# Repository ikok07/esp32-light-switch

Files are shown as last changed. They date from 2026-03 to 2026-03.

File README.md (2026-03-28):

# ESP32 Light Switch

A BLE-enabled smart light switch built on the **ESP32**, developed as part of a custom hardware product lineup. The firmware is written in C using the **ESP-IDF** framework and integrates natively with **Home Assistant** via a custom dedicated [HAOS BLE integration](https://github.com/ikok07/kok-products-ble-haos-integration).

---

## Features

- **BLE Control** — Toggle the light on/off wirelessly from any BLE-capable client (preferably the HAOS integration)
- **Physical Toggle** — Interrupt-driven physical button for manual control (GPIO 21)
- **Home Assistant Integration** — Works out of the box with my custom [HAOS BLE integration](https://github.com/ikok07/kok-products-ble-haos-integration)
- **Status LED** — RGB LED (GPIO 48) that reflects the current device state at a glance
- **Light Sleep** — CPU frequency scaling and light sleep enabled at runtime to reduce power consumption
- **Dual-core task scheduling** — BLE stack runs on Core 0; light control, status LED, and notification tasks run on Core 1

---

## Hardware

The PCB design files are located in the [`pcb/`](pcb/) directory (KiCad project). Key datasheets and reference material can be found in [`docs/`](docs/).

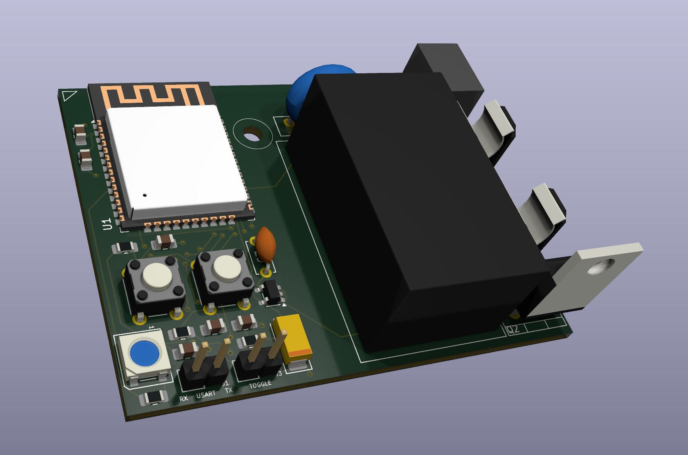
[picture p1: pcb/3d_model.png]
PCB 3D-model


| Component | Purpose |
|---|---|
| ESP32 | Main MCU |
| BTB16 - TRIAC | Mains switching |
| HLK-PM01 | AC→5 V power supply |
| MIC5205 LDO | 3.3 V regulation |
| PC817 Optocoupler | TRIAC isolation |

---

## Firmware Overview

The project is structured as a standard ESP-IDF project with reusable components:

```
main/           – Application entry point & board-specific configuration
components/
  ├── app_state/        – Global application state (tasks, handles, shared values)
  ├── ble/              – BLE driver (GAP / GATT abstraction over NimBLE)
  ├── logger/           – Logging utilities
  ├── power/            – CPU frequency control & light sleep management
  ├── shared_values/    – Thread-safe shared value store (FreeRTOS-based)
  ├── tasks_scheduler/  – FreeRTOS task lifecycle helpers
  └── timer/            – Timer utilities
```

### Startup sequence

1. Application state initialised
2. Logger configured
3. Power management configured & CPU frequency scaling enabled
4. Status LED initialised → **orange** (configuring)
5. Light control GPIO and ISR configured
6. BLE stack initialised → status LED turns **white** (ready to connect)
7. Light sleep enabled

### Status LED states

| Color | State |
|---|---|
| 🟠 Orange | Configuring / booting |
| 🔴 Red | Hardware configuration error |
| 🔵 White  | Ready to connect |
| 🟢 Green  | Connected |
| Other | BLE configuration error |

---

## BLE Profile

| Property | Value |
|---|---|
| Device name | `LSwitch` |
| GAP appearance | `0x04C1` (Generic Switch) |
| Advertising interval | 50 ms |
| Security mode | Disabled / Just Works |
| Max connections | Configured via CONFIG_BT_NIMBLE_MAX_CONNECTIONS |
| Serial number | `LS001` |

### GATT Services

| Service | UUID | Description |
|---|---|---|
| Identifier | `651535-36ae-49aa-354c-ecfec15bc888` (128-bit) | Used by the HAOS integration to identify the device family |
| Automation I/O | `0x1815` | Exposes the light state characteristic |

**Light State Characteristic** (`0x2A56` – Digital):
- **Read** — returns current relay state (`0` or `1`)
- **Write** — sets relay state (`0` = off, `1` = on)
- **Notify** — pushes state updates to subscribed clients

---

## Home Assistant Integration

Install the [HAOS BLE integration](https://github.com/ikok07/kok-products-ble-haos-integration) in your Home Assistant instance. The device advertises the identifier service UUID and manufacturer data in its BLE advertisement so that the integration can automatically recognise and add it.

See [`docs/haos_compatibility.md`](docs/haos_compatibility.md) for the full BLE advertisement requirements.

---

## Building & Flashing

Prerequisites: [ESP-IDF v5.x](https://docs.espressif.com/projects/esp-idf/en/latest/esp32s3/get-started/) installed and sourced.

```bash
# Configure
idf.py set-target esp32

# Build
idf.py build

# Flash & monitor
idf.py -p /dev/tty.usbserial-* flash monitor
```

---

## License

This project is part of a custom hardware product lineup. All rights reserved © Kaloyan Stefanov.

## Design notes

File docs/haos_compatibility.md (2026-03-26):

#### To make the device compatible with [Home Assistant integration](https://github.com/ikok07/kok-products-ble-haos-integration) you should configure the following BLE parameters:

----

1. Identifier service should be set in the advertisement fields (check UUID from the [integration's repo](https://github.com/ikok07/kok-products-ble-haos-integration))
2. The encryption mode should be set to "Just Works" (integration doesn't support other methods yet)
3. Advertised manufacturer data:
   - byte 1–2 ⇒ Manufacturer ID (check from the [integration's repo](https://github.com/ikok07/kok-products-ble-haos-integration))
   - byte 3 ⇒ Device Model (must be implemented in [integration's repo](https://github.com/ikok07/kok-products-ble-haos-integration))
   - byte 4 ⇒ If the device requires pairing (0 or 1)

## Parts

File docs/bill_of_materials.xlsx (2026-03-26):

Part | Designator | Quantity | Price | Real Price | URL
ESP32-WROOM-32E | U1 | 1 | €0.00 | €0.00
HLK-PM01 (Power supply) | PS2 | 1 | €4.35 | €4.35 | https://bulcomp-eng.com/m/index.php?p=10&idprod=19925
PC817 (Optocoupler) | U2 | 1 | €0.26 | €0.26 | https://tpetrov.com/ltv817s-lit-247331
BTB16-800BRG (TRIAC) | Q2 | 1 | €1.07 | €1.07 | https://tpetrov.com/btb16-800brg-242340
AC Terminal Screw 01x02 | J2 | 1 | €0.26 | €0.26 | https://tpetrov.com/klema-dg306-02p-36674
MIC5205 (Voltage regulator) | U3 | 1 | €0.00 | €0.00
Capacitor Tantalum (4.7uF) | C5 | 1 | €0.64 | €0.64 | https://tpetrov.com/kondenzator-47mf-25v-smd-tantal-35838
Capacitor (0.1uF) | C1, C4, C6, C8, C9 | 5 | €0.06 | €0.30 | https://tpetrov.com/kondenzator-100nf-50v-0805-smd-34785
Capacitor (470pF) | C7 | 1 | €0.08 | €0.08 | https://tpetrov.com/kondenzator-470pf-100v-47046
Capacitor (22uF) | C2 | 1 | €0.10 | €0.10 | https://tpetrov.com/kondenzator-22mf-63v-smd-0805-243684
Resistor (220) | R4 | 1 | €0.08 | €0.08 | https://tpetrov.com/rezistor-220om-smd-0805-250613
Resistor (10K) | R1, R2, R3 | 3 | €0.03 | €0.09 | https://tpetrov.com/rezistor-10kom-smd-0805-22597
Resistor (100) | R5, R6 | 2 | €0.06 | €0.12 | https://tpetrov.com/rezistor-100om-0125w-smd-22589
Touch button | SW1, SW2 | 2 | €0.09 | €0.18 | https://tpetrov.com/tach-buton-121-9505
Toggle button | J3 | 1 | €0.97 | €0.97 | https://tpetrov.com/buton-swb1019a-r-240936
Varistor 275V | RV1 | 1 | €0.36 | €0.36 | https://tpetrov.com/varistor-275v-125mm-240814
Fuse (500mA) | F1 | 1 | €0.10 | €0.10 | https://tpetrov.com/predpazitel-5x20-05a-zkm-36366
Fuse holder | - | 1 | €0.26 | €0.26 | https://tpetrov.com/darjach-za-predpazitel-f313-5x20-39121
Connector (Male & Female) | - | 1 | €0.10 | €0.10 | https://tpetrov.com/kuplung-396-ns39-02mg-46470
Heatsink (TRIAC) | - | 1 | €0.51 | €0.51 | https://tpetrov.com/radiator-n23-40566
WS2812B LED | D1 | 1 | €0.00 | €0.00 | -
 |  |  |  | €9.83

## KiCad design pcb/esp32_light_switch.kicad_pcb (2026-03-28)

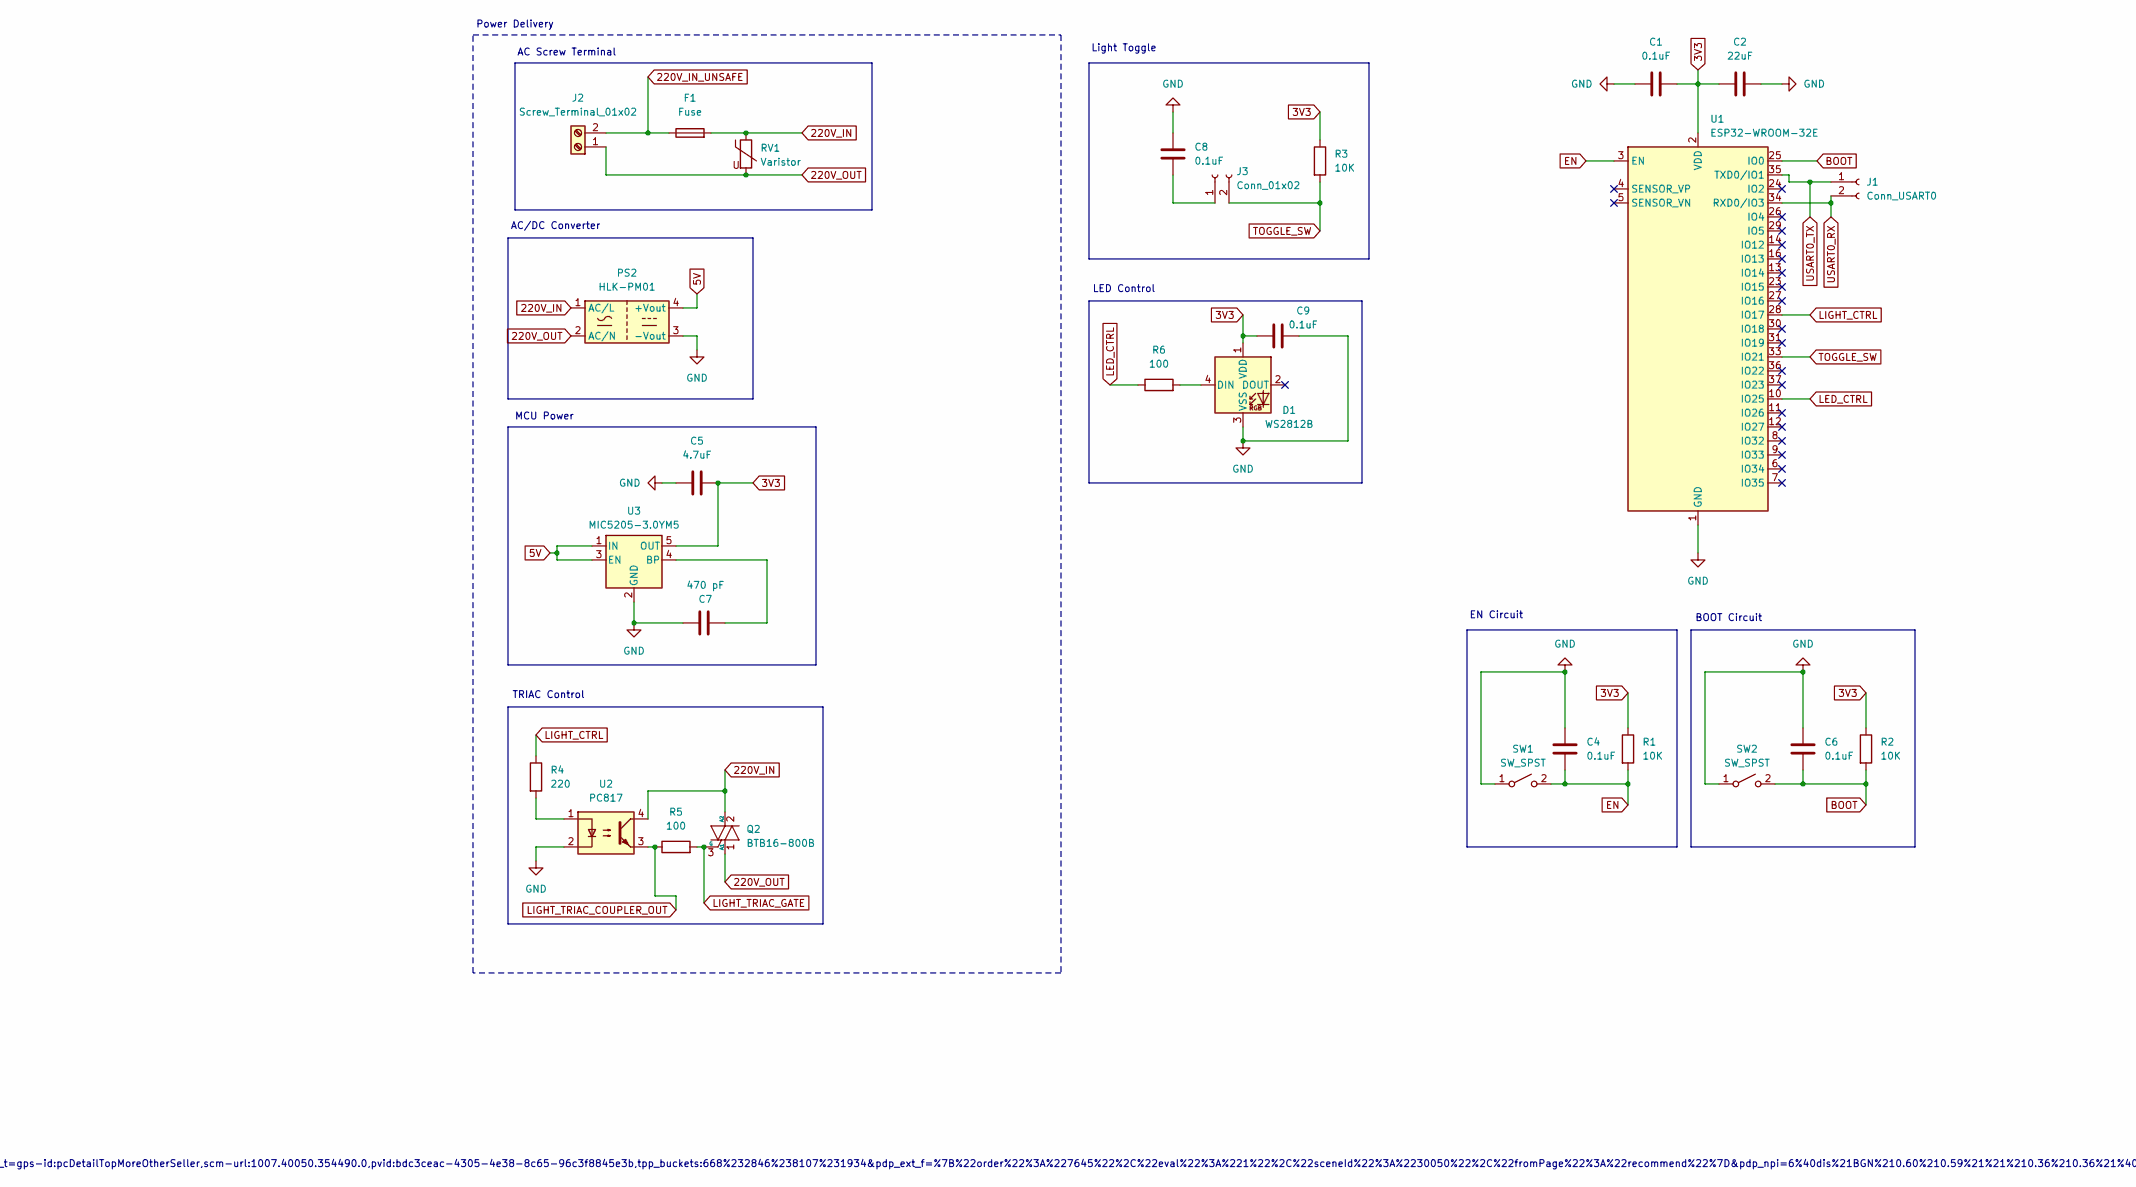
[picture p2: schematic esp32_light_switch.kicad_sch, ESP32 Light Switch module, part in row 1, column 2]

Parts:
C1, C4, C6, C8, C9: 0.1uF; C_0805_2012Metric_Pad1.18x1.45mm_HandSolder
C2: 22uF; C_0805_2012Metric_Pad1.18x1.45mm_HandSolder
C5: 4.7uF; CP_EIA-6032-20_AVX-F_HandSolder
C7: 470 pF; C_Disc_D5.0mm_W2.5mm_P5.00mm
D1: WS2812B; LED_WS2812B_PLCC4_5.0x5.0mm_P3.2mm
F1: Fuse; Fuseholder_Cylinder-5x20mm_Schurter_0031_8201_Horizontal_Op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
J1: Conn_USART0; PinHeader_1x02_P2.54mm_Vertical
J2: Screw_Terminal_01x02; DG3065002P1200AH
J3: Conn_01x02; PinHeader_1x02_P2.54mm_Vertical
PS2: HLK-PM01; Converter_ACDC_Hi-Link_HLK-PMxx
Q2: BTB16-800B; TO-220-3_Vertical
R1, R2, R3: 10K; R_0805_2012Metric_Pad1.20x1.40mm_HandSolder
R4: 220; R_0805_2012Metric_Pad1.20x1.40mm_HandSolder
R5, R6: 100; R_0805_2012Metric_Pad1.20x1.40mm_HandSolder
RV1: Varistor; RV_Disc_D12mm_W3.9mm_P7.5mm
SW1, SW2: SW_SPST; SW_TH_Tactile_Omron_B3F-100x
U1: ESP32-WROOM-32E; ESP32-WROOM-32D
U2: PC817; DIP-4_W7.62mm_SMDSocket_SmallPads
U3: MIC5205-3.0YM5; SOT-23-5

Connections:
3V3: C1.2, C2.1, C5.2, C9.1, D1.1 (VDD), R1.1, R2.1, R3.1, U1.2 (VDD), U3.5 (OUT)
5V: PS2.4 (+Vout), U3.1 (IN), U3.3 (EN)
220V_IN: F1.2, PS2.1 (AC/L), Q2.2 (A2), RV1.1, U2.4
220V_IN_UNSAFE: F1.1, J2.2
220V_OUT: J2.1, PS2.2 (AC/N), Q2.1 (A1), RV1.2
BOOT: C6.1, R2.2, SW2.2 (B), U1.25 (IO0)
EN: C4.2, R1.2, SW1.2 (B), U1.3 (EN)
GND: C1.1, C2.2, C4.1, C5.1, C6.2, C7.2, C8.1, C9.2, D1.3 (VSS), PS2.3 (-Vout), SW1.1 (A), SW2.1 (A), U1.1 (GND), U1.15 (GND), U1.38 (GND), U1.39 (GND), U2.2, U3.2 (GND)
LED_CTRL: R6.1, U1.10 (IO25)
LIGHT_CTRL: R4.1, U1.28 (IO17)
LIGHT_TRIAC_COUPLER_OUT: R5.1, U2.3
LIGHT_TRIAC_GATE: Q2.3 (G), R5.2
unnamed: D1.4 (DIN), R6.2
unnamed: C8.2, J3.1
unnamed: R4.2, U2.1
unnamed: C7.1, U3.4 (BP)
TOGGLE_SW: J3.2, R3.2, U1.33 (IO21)
USART0_RX: J1.2, U1.34 (RXD0/IO3)
USART0_TX: J1.1, U1.35 (TXD0/IO1)

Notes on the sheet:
TRIAC Control
Light Toggle
AC Screw Terminal
Power Delivery
LED Control
AC/DC Converter
BOOT Circuit
https://www.aliexpress.com/item/32901160058.html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…
MCU Power
EN Circuit

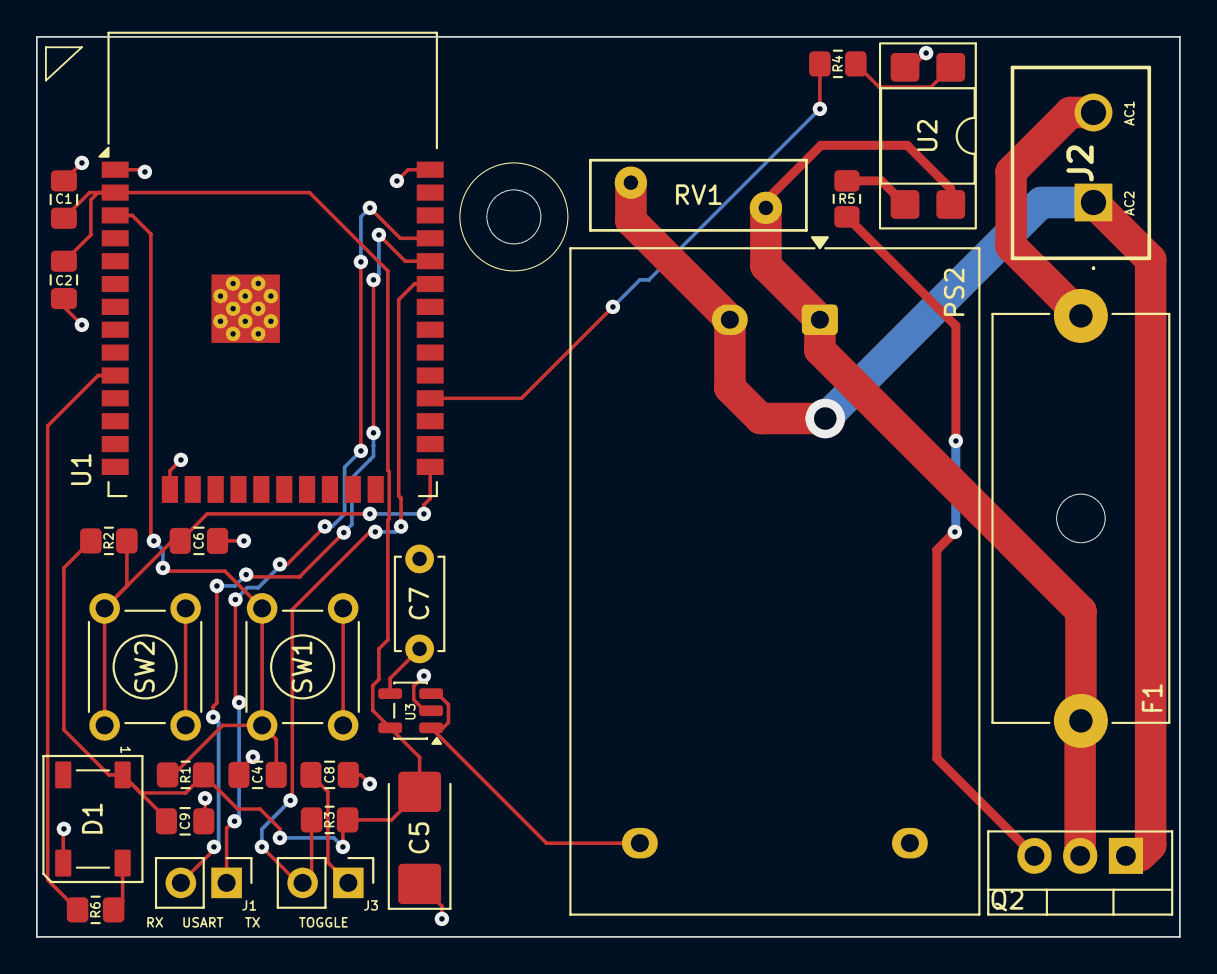
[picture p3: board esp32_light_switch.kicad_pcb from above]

Board: 2 copper layers, 63.5 x 50.0 mm, 27 parts (0 on the bottom side), 19 nets.

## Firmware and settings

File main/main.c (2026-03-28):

#include "app_state.h"
#include "power.h"
#include "log.h"
#include "ble.h"
#include "led_strip.h"

#include "bt.h"
#include "log-config.h"
#include "light_control.h"
#include "status_led.h"


void app_main(void) {
    esp_err_t esp_err;

    // Initialize app state
    APP_Init();

    // Configure logger
    LOG_Configure();

    // Configure power
    if ((esp_err = POWER_Config())!= ESP_OK) {
        LOGGER_LogF(LOGGER_LEVEL_FATAL, "Failed to configure board power! Error code: %d", esp_err);
        return;
    }
    POWER_FreqControl(pdTRUE);

    // Disable MCU sleep during configuration
    POWER_LightSleepControl(pdFALSE);

    // Configure Status LED
    STATUSLED_Init();

    // Set configuring LED state
    STATUSLED_SetState(STATUSLED_STATE_CONFIGURING);

    // Configure light control
    LCTRL_Init();

    // Configure and start BLE task
    BT_Init();

    // Wait for all tasks to start
    while (
        !gAppState.Tasks->StatusLedTask.Active ||
        !gAppState.Tasks->LightCtrlTask.Active ||
        !gAppState.Tasks->BleTask.Active
    ) {
        vTaskDelay(pdMS_TO_TICKS(10));
    }

    // Allow MCU to sleep
    POWER_LightSleepControl(pdTRUE);
}

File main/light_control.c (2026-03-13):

//
// Created by Kok on 3/9/26.
//

#include "include/light_control.h"

#include "app_state.h"
#include "task_scheduler.h"
#include "tasks_common.h"
#include "driver/gpio.h"
#include "log.h"
#include "power.h"
#include "status_led.h"

#include "soc/gpio_num.h"


static void light_ctrl_task(void *arg);
static void IRAM_ATTR light_toggle_isr(void *arg);

void LCTRL_Init() {
    esp_err_t esp_err;
    gpio_config_t io_cfg = {
        .mode = GPIO_MODE_OUTPUT,
        .pin_bit_mask = (1 << LIGHT_CTRL_GPIO),
        .pull_down_en = GPIO_PULLDOWN_DISABLE,
        .pull_up_en = GPIO_PULLUP_DISABLE,
    };
    if ((esp_err = gpio_config(&io_cfg)) != ESP_OK) {
        LOGGER_LogF(LOGGER_LEVEL_ERROR, "Failed to initialize light control GPIO! Error code: %d", esp_err);
        STATUSLED_SetState(STATUSLED_STATE_ERROR_HW_CFG);
        POWER_WaitAndRestart(3000);
    } else {
        LOGGER_Log(LOGGER_LEVEL_INFO, "Light control GPIO initialized successfully!");
    };

    io_cfg.mode = GPIO_MODE_INPUT;
    io_cfg.pin_bit_mask = (1 << LIGHT_TOGGLE_GPIO);
    io_cfg.intr_type = GPIO_INTR_POSEDGE;
    io_cfg.pull_up_en = GPIO_PULLUP_ENABLE;
    if ((esp_err = gpio_config(&io_cfg)) != ESP_OK) {
        LOGGER_LogF(LOGGER_LEVEL_ERROR, "Failed to initialize light toggle GPIO! Error code: %d", esp_err);
        STATUSLED_SetState(STATUSLED_STATE_ERROR_HW_CFG);
        POWER_WaitAndRestart(3000);
    } else {
        LOGGER_Log(LOGGER_LEVEL_INFO, "Light toggle GPIO initialized successfully!");
    };

    if ((esp_err = gpio_install_isr_service(0)) != ESP_OK) {
        LOGGER_LogF(LOGGER_LEVEL_ERROR, "Failed to install GPIO ISR service! Error code: %d", esp_err);
        STATUSLED_SetState(STATUSLED_STATE_ERROR_HW_CFG);
        POWER_WaitAndRestart(3000);
    };

    if ((esp_err = gpio_isr_handler_add(LIGHT_TOGGLE_GPIO, light_toggle_isr, NULL)) != ESP_OK) {
        LOGGER_LogF(LOGGER_LEVEL_ERROR, "Failed to add light toggle ISR handler! Error code: %d", esp_err);
        STATUSLED_SetState(STATUSLED_STATE_ERROR_HW_CFG);
        POWER_WaitAndRestart(3000);
    };

    gAppState.Tasks->LightCtrlTask = (SCHEDULER_TaskTypeDef){
        .Active = 0,
        .CoreID = LIGHT_CONTROL_TASK_CORE_ID,
        .Name = "Light control task",
        .Priority = LIGHT_CONTROL_TASK_PRIORITY,
        .StackDepth = LIGHT_CONTROL_TASK_STACK_DEPTH,
        .Function = light_ctrl_task
    };

    SHVAL_ConfigTypeDef shval_config = {
        .InitialValue = 0,
        .SubscribersQueueSize = 1
    };
    gAppState.SharedValues->LightState = SHVAL_Init(&shval_config);

    SCHEDULER_Create(&gAppState.Tasks->LightCtrlTask);
}

void light_ctrl_task(void *arg) {
    esp_err_t esp_err;

    LOGGER_Log(LOGGER_LEVEL_INFO, "Light control task started");

    while (1) {
        uint32_t enable;
        if (xTaskNotifyWait(0, 0xFF, &enable, portMAX_DELAY)) {
            // Debounce time
            vTaskDelay(pdMS_TO_TICKS(150));

            // Clear pending notifications
            xTaskNotifyStateClear(NULL);

            uint8_t level;
            // Enable light
            if (enable == 1) level = 1;
            else if (enable == 2) {
                // Toggle light
                uint32_t curr_state;
                if (SHVAL_GetValue(&gAppState.SharedValues->LightState, &curr_state, 1000) != SHVAL_ERROR_OK) {
                    LOGGER_Log(LOGGER_LEVEL_ERROR, "Failed to get shared light state variable!");
                    gpio_isr_handler_add(LIGHT_TOGGLE_GPIO, light_toggle_isr, NULL);
                    continue;
                }
                level = !curr_state;
            }
            // Disable light
            else level = 0;

            if ((esp_err = gpio_set_level(LIGHT_CTRL_GPIO, level)) != ESP_OK) {
                LOGGER_LogF(LOGGER_LEVEL_ERROR, "Failed to set GPIO level! Error code: %d", esp_err);
            };

            if (SHVAL_SetValue(&gAppState.SharedValues->LightState, level, 1000) != SHVAL_ERROR_OK) {
                LOGGER_Log(LOGGER_LEVEL_ERROR, "Failed to set shared light state variable!");
            }

            LOGGER_Log(LOGGER_LEVEL_INFO, level == 1 ? "Light enabled" : "Light disabled");

            gpio_isr_handler_add(LIGHT_TOGGLE_GPIO, light_toggle_isr, NULL);

            // Notify BLE devices
            xTaskNotifyGive(gAppState.Tasks->BleLightStateNotificationsTask.OsTask);
        }
    }
}

void light_toggle_isr(void *arg) {
    gpio_isr_handler_remove(LIGHT_TOGGLE_GPIO);
    BaseType_t higher_priority_woken = pdFALSE;
    xTaskNotifyFromISR(gAppState.Tasks->LightCtrlTask.OsTask, 2, eSetValueWithOverwrite, &higher_priority_woken);
    portYIELD_FROM_ISR(higher_priority_woken);
}

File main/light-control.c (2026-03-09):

//
// Created by Kok on 3/9/26.
//

#include "light-control.h"

#include "app_state.h"
#include "task_scheduler.h"
#include "tasks_common.h"
#include "driver/gpio.h"
#include "log.h"

#include "soc/gpio_num.h"


static void light_ctrl_config_task(void *arg);
static void light_ctrl_task(void *arg);
static void IRAM_ATTR light_toggle_isr(void *arg);

static SCHEDULER_TaskTypeDef gLightCtrlCfgTask = {
    .Active = 0,
    .CoreID = LIGHT_CONTROL_CFG_TASK_CORE_ID,
    .Name = "Light control config task",
    .Priority = LIGHT_CONTROL_CFG_TASK_PRIORITY,
    .StackDepth = LIGHT_CONTROL_CFG_TASK_STACK_DEPTH,
    .Function = light_ctrl_config_task
};

void LCTRL_Init() {
    SCHEDULER_Create(&gLightCtrlCfgTask);
}

void light_ctrl_config_task(void *arg) {
    esp_err_t esp_err;
    gpio_config_t io_cfg = {
        .mode = GPIO_MODE_OUTPUT,
        .pin_bit_mask = (1 << LIGHT_CTRL_GPIO),
        .pull_down_en = GPIO_PULLDOWN_ENABLE,
        .pull_up_en = GPIO_PULLUP_DISABLE,
    };
    if ((esp_err = gpio_config(&io_cfg)) != ESP_OK) {
        LOGGER_LogF(LOGGER_LEVEL_FATAL, "Failed to initialize light control GPIO! Error code: %d", esp_err);
    } else {
        LOGGER_Log(LOGGER_LEVEL_INFO, "Light control GPIO initialized successfully!");
    };

    io_cfg.pin_bit_mask = (1 << LIGHT_TOGGLE_GPIO);
    io_cfg.intr_type = GPIO_INTR_POSEDGE;
    if ((esp_err = gpio_config(&io_cfg)) != ESP_OK) {
        LOGGER_LogF(LOGGER_LEVEL_FATAL, "Failed to initialize light toggle GPIO! Error code: %d", esp_err);
    } else {
        LOGGER_Log(LOGGER_LEVEL_INFO, "Light toggle GPIO initialized successfully!");
    };

    if ((esp_err = gpio_install_isr_service(0)) != ESP_OK) {
        LOGGER_LogF(LOGGER_LEVEL_FATAL, "Failed to install GPIO ISR service! Error code: %d", esp_err);
    };

    if ((esp_err = gpio_isr_handler_add(LIGHT_TOGGLE_GPIO, light_toggle_isr, NULL)) != ESP_OK) {
        LOGGER_LogF(LOGGER_LEVEL_FATAL, "Failed to add light toggle ISR handler! Error code: %d", esp_err);
    };

    gAppState.Tasks->LightCtrlTask = (SCHEDULER_TaskTypeDef){
        .Active = 0,
        .CoreID = LIGHT_CONTROL_TASK_CORE_ID,
        .Name = "Light control task",
        .Priority = LIGHT_CONTROL_TASK_PRIORITY,
        .StackDepth = LIGHT_CONTROL_TASK_STACK_DEPTH,
        .Function = light_ctrl_task
    };

    SCHEDULER_Remove(&gLightCtrlCfgTask);
    SCHEDULER_Create(&gAppState.Tasks->LightCtrlTask);
}

void light_ctrl_task(void *arg) {
    while (1) {
        uint32_t enable;
        if (xTaskNotifyWait(0, 0xFF, &enable, portMAX_DELAY)) {
            // Enable light
            if (enable == 1) gpio_set_level(LIGHT_CTRL_GPIO, 1);
            // Toggle light
            else if (enable == 2) gpio_set_level(LIGHT_CTRL_GPIO, !gpio_get_level(LIGHT_CTRL_GPIO));
            // Disable light
            else gpio_set_level(LIGHT_CTRL_GPIO, 0);
            LOGGER_Log(LOGGER_LEVEL_INFO, enable == 1 ? "Light enabled" : "Light disabled");
        }
    }
}

void light_toggle_isr(void *arg) {
    BaseType_t higher_priority_woken = pdFALSE;
    xTaskNotifyFromISR(gAppState.Tasks->LightCtrlTask.OsTask, 2, eSetValueWithOverwrite, &higher_priority_woken);
    portYIELD_FROM_ISR(higher_priority_woken);
}

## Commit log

2026-02-21 modify ble board specific dependencies
2026-03-09 Implement light control task
    [bill_of_materials.xlsx]
2026-03-10 Refactor light control and add status LED functionality
2026-03-26 Enhance BLE compatibility with Home Assistant integration by updating advertisement parameters and security settings
    [bill_of_materials.xlsx]
2026-03-28 Add KiCad PCB design files and update README for ESP32 light switch project
    [esp32_light_switch-B_Cu.gbr, esp32_light_switch-B_Mask.gbr, esp32_light_switch-B_Paste.gbr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]
2026-03-28 Add PCB 3d model
